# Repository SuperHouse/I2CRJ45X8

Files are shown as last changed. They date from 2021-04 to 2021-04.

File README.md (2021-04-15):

I2C to RJ45 Breakout (8 Port)
=============================
Copyright 2019-2021 SuperHouse Automation Pty Ltd  www.superhouse.tv  

8 RJ45 sockets connected to 32 I/O channels via I2C addressable
I/O controllers. Intended for use in building a home automation light
switch controller for connection to SuperHouse light switches.

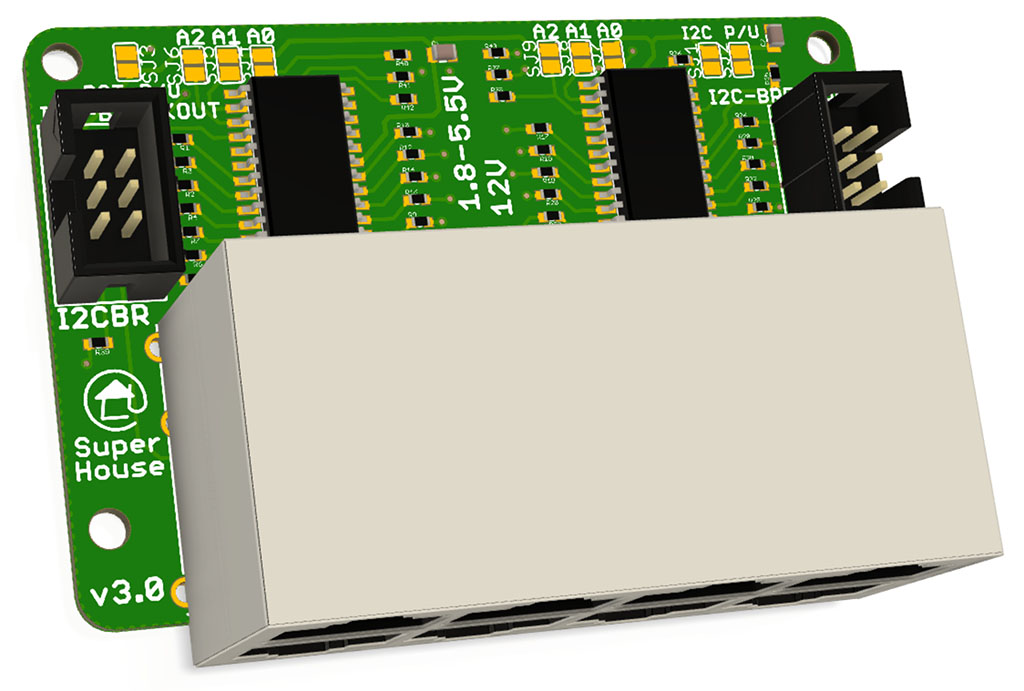
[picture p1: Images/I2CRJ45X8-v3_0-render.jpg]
I2C RJ45 Breakout PCB


Features:

 * 8 x RJ45 sockets for connection to light switches over Cat-5
 * I2C interface with interrupt output

This project has different versions:

 * 8-port version: https://github.com/superhouse/i2crj45x8
 * 16-port version: https://github.com/superhouse/i2crj45x16
 * 24-port version: https://github.com/superhouse/i2crj45x24
 * 24-port version with passthrough: https://github.com/superhouse/i2crj45x24pt

More information:

  http://www.superhouse.tv/i2crj45x8

INSTALLATION
------------
The design is saved as an EAGLE project. EAGLE PCB design software is
available from www.cadsoftusa.com free for non-commercial use. To use
this project download it and place the directory containing these files
into the "eagle" directory on your computer. Then open EAGLE and
navigate to the project.

CREDITS
-------
Designed by Jonathan Oxer jon@oxer.com.au

DISTRIBUTION
------------
The specific terms of distribution of this project are governed by the
license referenced below.

LICENSE
-------
Licensed under the TAPR Open Hardware License (www.tapr.org/OHL).
The "license" folder within this repository also contains a copy of
this license in plain text format.

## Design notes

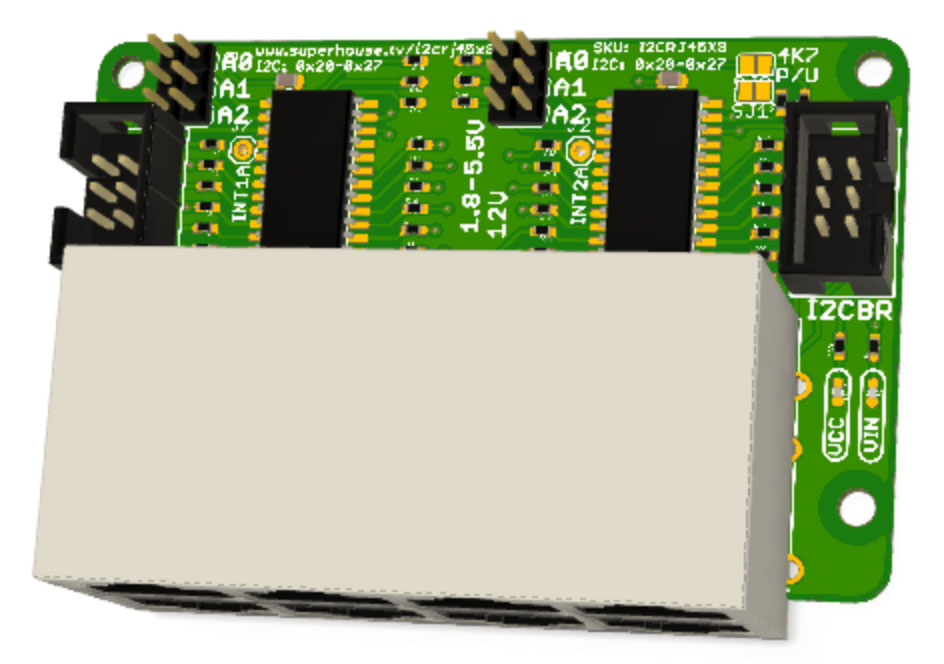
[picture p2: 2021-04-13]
Images/I2CRJ45X8-v2_2-render.jpg

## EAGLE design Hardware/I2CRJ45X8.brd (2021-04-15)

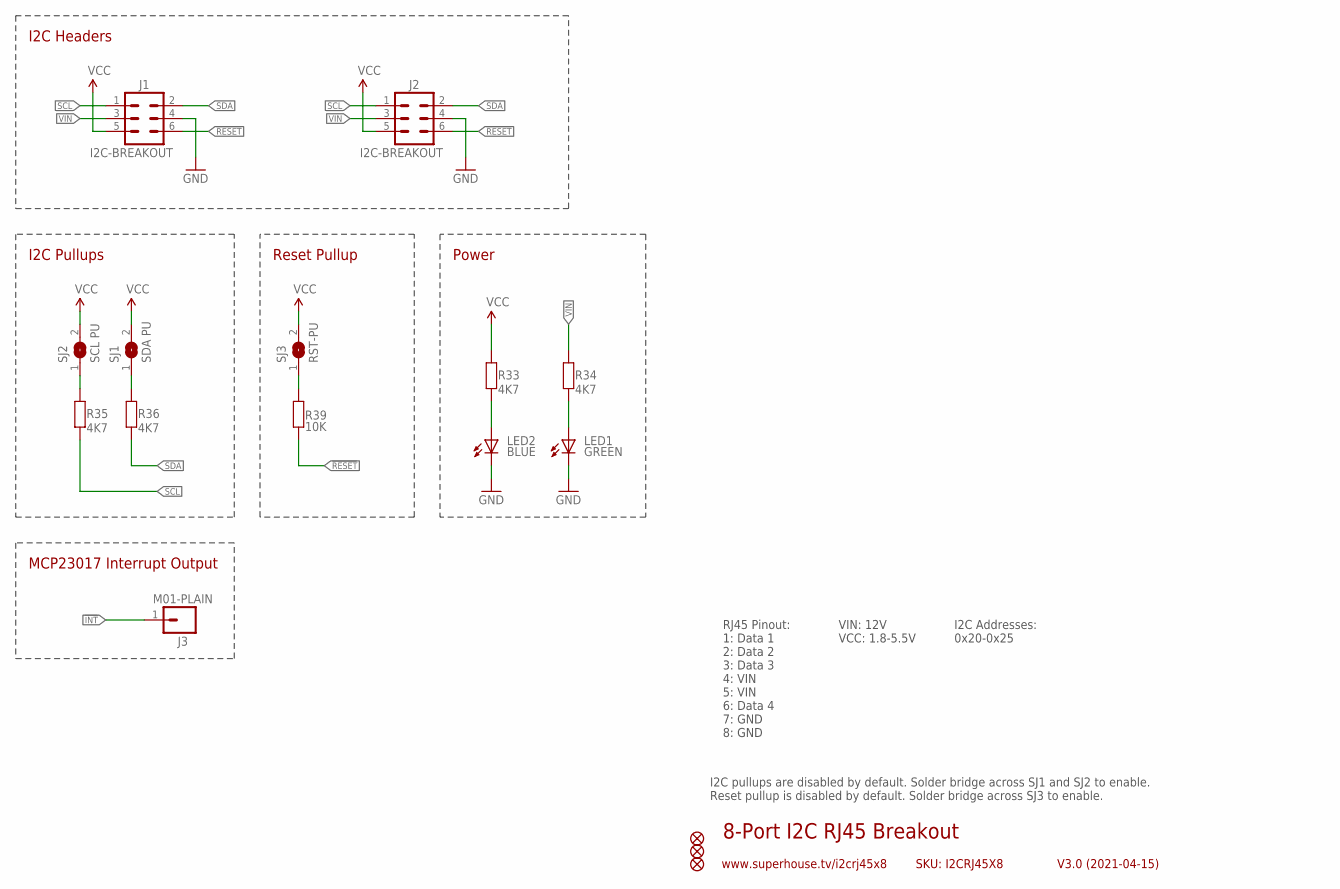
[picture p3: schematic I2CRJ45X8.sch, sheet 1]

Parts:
FID1, FID2, FID3: FIDUCIAL1X2.5; FIDUCIAL-1X2.5
J1, J2: I2C-BREAKOUT; 2X03-SHROUDED
J3: M01-PLAIN; 1X01
LED1: GREEN; LED-0603
LED2: BLUE; LED-0603
R33, R34, R35, R36: 4K7; R0603
R39: 10K; R0603
SJ1: SDA PU; SJ
SJ2: SCL PU; SJ
SJ3: RST-PU; SJ

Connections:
!INT: J3.1; also elsewhere on the board
!RESET: J1.6, J2.6, R39.1; also elsewhere on the board
GND: J1.4, J2.4, LED1.C, LED2.C; also elsewhere on the board
unnamed: R35.2, SJ2.1
unnamed: R36.2, SJ1.1
unnamed: R39.2, SJ3.1
unnamed: LED2.A, R33.1
unnamed: LED1.A, R34.1
SCL: J1.1, J2.1, R35.1; also elsewhere on the board
SDA: J1.2, J2.2, R36.1; also elsewhere on the board
VCC: J1.5, J2.5, R33.2, SJ1.2, SJ2.2, SJ3.2; also elsewhere on the board
VIN: J1.3, J2.3, R34.2; also elsewhere on the board

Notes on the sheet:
8-Port I2C RJ45 Breakout
V3.0 (2021-04-15)
www.superhouse.tv/i2crj45x8
SKU: I2CRJ45X8
RJ45 Pinout: 1: Data 1 2: Data 2 3: Data 3 4: VIN 5: VIN 6: Data 4 7: GND 8: GND
VIN: 12V VCC: 1.8-5.5V
I2C Addresses: 0x20-0x25
I2C Headers
MCP23017 Interrupt Output
I2C Pullups
I2C pullups are disabled by default. Solder bridge across SJ1 and SJ2 to enable. Reset pullup is disabled by default. Solder bridge across SJ3 to enable.
Power
Reset Pullup

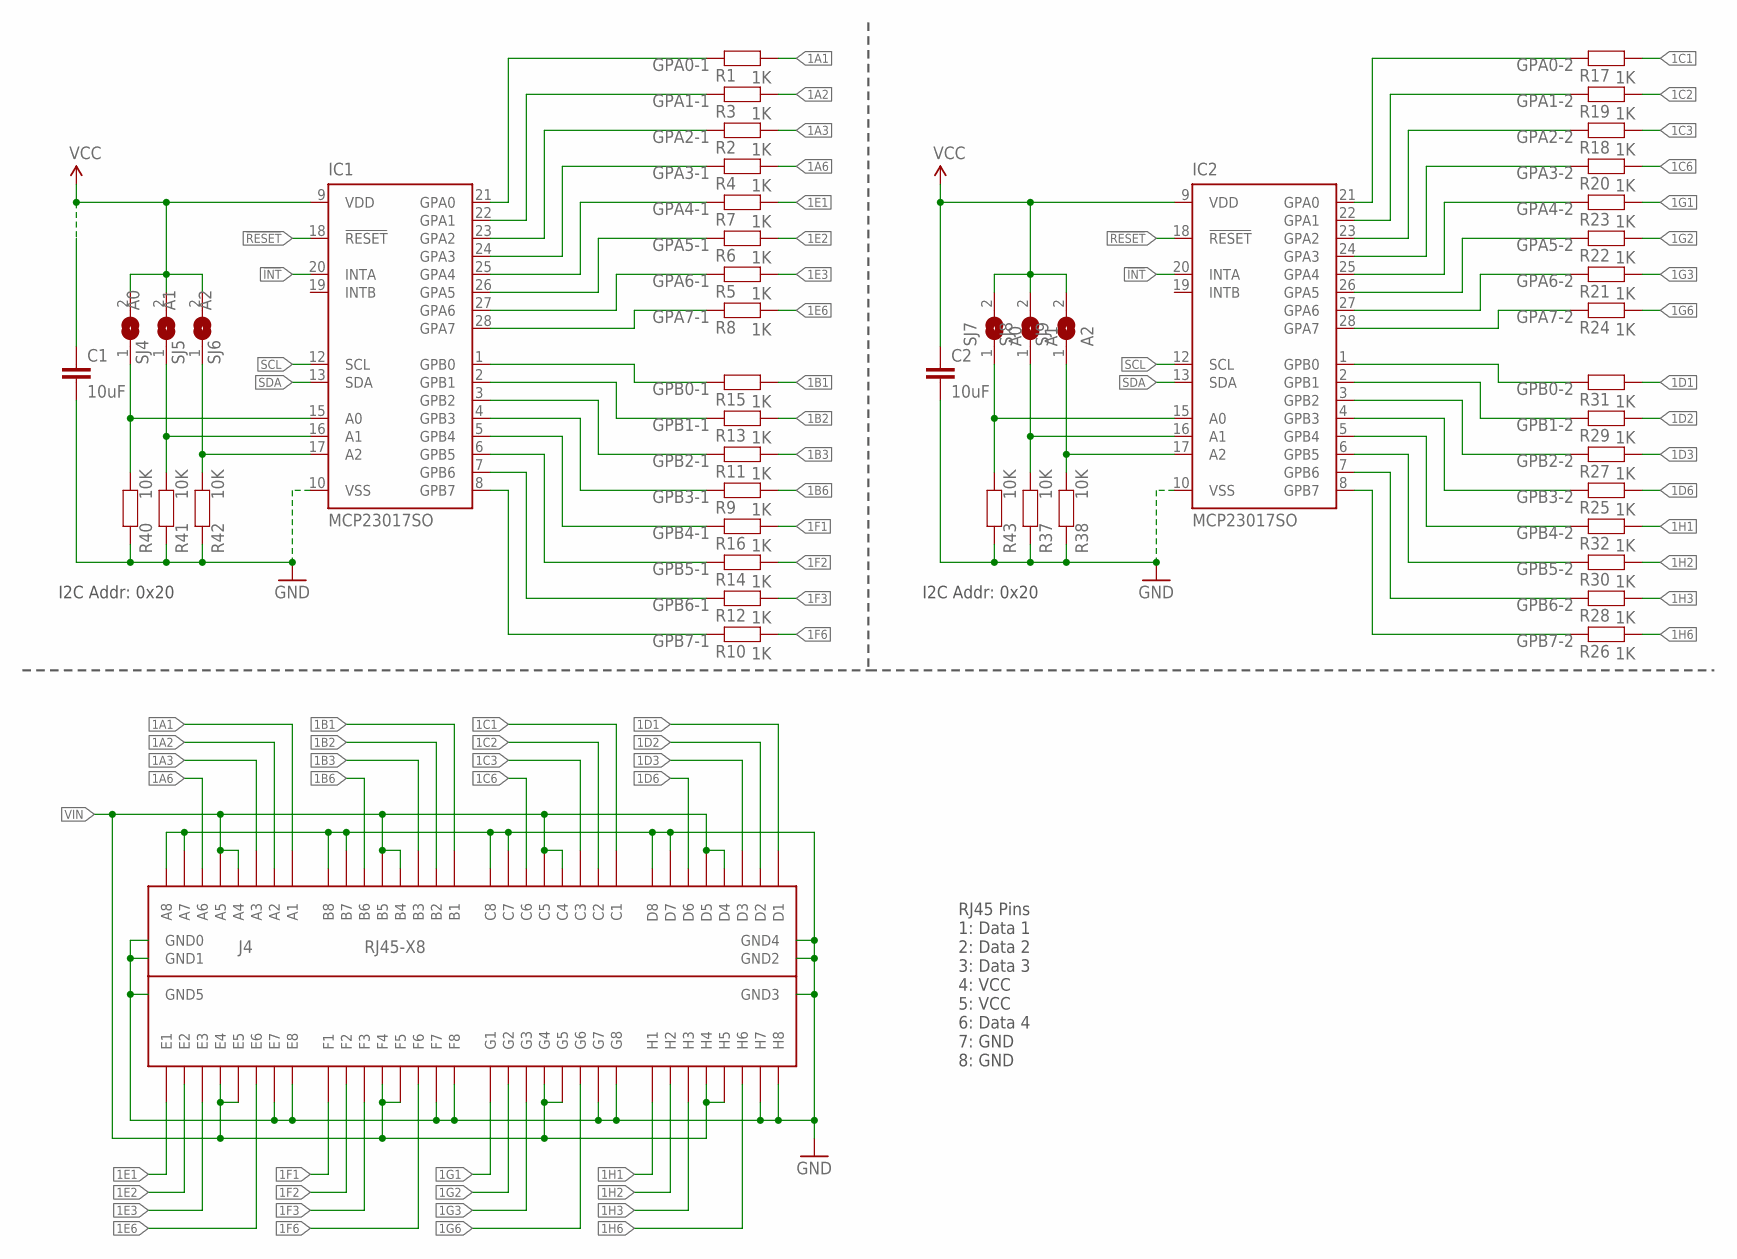
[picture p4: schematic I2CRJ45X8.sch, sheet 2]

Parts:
C1, C2: 10uF; C0805
IC1, IC2: MCP23017SO; SO28W
J4: RJ45-X8; RJ45-2X4
R1, R2, R3, R4, R5, R6, R7, R8, R9, R10, R11, R12, R13, R14, R15, R16, R17, R18, R19, R20, R21, R22, R23, R24, R25, R26, R27, R28, R29, R30, R31, R32: 1K; R0603
R37, R38, R40, R41, R42, R43: 10K; R0603
SJ4, SJ7: A0; SJ
SJ5, SJ8: A1; SJ
SJ6, SJ9: A2; SJ

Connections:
1A1: J4.A1, R1.2
1A2: J4.A2, R3.2
1A3: J4.A3, R2.2
1A6: J4.A6, R4.2
1B1: J4.B1, R15.2
1B2: J4.B2, R13.2
1B3: J4.B3, R11.2
1B6: J4.B6, R9.2
1C1: J4.C1, R17.2
1C2: J4.C2, R19.2
1C3: J4.C3, R18.2
1C6: J4.C6, R20.2
1D1: J4.D1, R31.2
1D2: J4.D2, R29.2
1D3: J4.D3, R27.2
1D6: J4.D6, R25.2
1E1: J4.E1, R7.2
1E2: J4.E2, R6.2
1E3: J4.E3, R5.2
1E6: J4.E6, R8.2
1F1: J4.F1, R16.2
1F2: J4.F2, R14.2
1F3: J4.F3, R12.2
1F6: J4.F6, R10.2
1G1: J4.G1, R23.2
1G2: J4.G2, R22.2
1G3: J4.G3, R21.2
1G6: J4.G6, R24.2
1H1: J4.H1, R32.2
1H2: J4.H2, R30.2
1H3: J4.H3, R28.2
1H6: J4.H6, R26.2
!INT: IC1.20 (INTA), IC2.20 (INTA); also elsewhere on the board
!RESET: IC1.18 (!RESET), IC2.18 (!RESET); also elsewhere on the board
GND: C1.2, C2.2, IC1.10 (VSS), IC2.10 (VSS), J4.A7, J4.A8, J4.B7, J4.B8, J4.C7, J4.C8, J4.D7, J4.D8, J4.E7, J4.E8, J4.F7, J4.F8, J4.G7, J4.G8, J4.GND0, J4.GND1, J4.GND2, J4.GND3, J4.GND4, J4.GND5, J4.H7, J4.H8, R37.1, R38.1, R40.1, R41.1, R42.1, R43.1; also elsewhere on the board
GPA0-1: IC1.21 (GPA0), R1.1
GPA0-2: IC2.21 (GPA0), R17.1
GPA1-1: IC1.22 (GPA1), R3.1
GPA1-2: IC2.22 (GPA1), R19.1
GPA2-1: IC1.23 (GPA2), R2.1
GPA2-2: IC2.23 (GPA2), R18.1
GPA3-1: IC1.24 (GPA3), R4.1
GPA3-2: IC2.24 (GPA3), R20.1
GPA4-1: IC1.25 (GPA4), R7.1
GPA4-2: IC2.25 (GPA4), R23.1
GPA5-1: IC1.26 (GPA5), R6.1
GPA5-2: IC2.26 (GPA5), R22.1
GPA6-1: IC1.27 (GPA6), R5.1
GPA6-2: IC2.27 (GPA6), R21.1
GPA7-1: IC1.28 (GPA7), R8.1
GPA7-2: IC2.28 (GPA7), R24.1
GPB0-1: IC1.1 (GPB0), R15.1
GPB0-2: IC2.1 (GPB0), R31.1
GPB1-1: IC1.2 (GPB1), R13.1
GPB1-2: IC2.2 (GPB1), R29.1
GPB2-1: IC1.3 (GPB2), R11.1
GPB2-2: IC2.3 (GPB2), R27.1
GPB3-1: IC1.4 (GPB3), R9.1
GPB3-2: IC2.4 (GPB3), R25.1
GPB4-1: IC1.5 (GPB4), R16.1
GPB4-2: IC2.5 (GPB4), R32.1
GPB5-1: IC1.6 (GPB5), R14.1
GPB5-2: IC2.6 (GPB5), R30.1
GPB6-1: IC1.7 (GPB6), R12.1
GPB6-2: IC2.7 (GPB6), R28.1
GPB7-1: IC1.8 (GPB7), R10.1
GPB7-2: IC2.8 (GPB7), R26.1
unnamed: IC1.17 (A2), R42.2, SJ6.1
unnamed: IC1.16 (A1), R41.2, SJ5.1
unnamed: IC1.15 (A0), R40.2, SJ4.1
unnamed: IC2.17 (A2), R38.2, SJ9.1
unnamed: IC2.16 (A1), R37.2, SJ8.1
unnamed: IC2.15 (A0), R43.2, SJ7.1
SCL: IC1.12 (SCL), IC2.12 (SCL); also elsewhere on the board
SDA: IC1.13 (SDA), IC2.13 (SDA); also elsewhere on the board
VCC: C1.1, C2.1, IC1.9 (VDD), IC2.9 (VDD), SJ4.2, SJ5.2, SJ6.2, SJ7.2, SJ8.2, SJ9.2; also elsewhere on the board
VIN: J4.A4, J4.A5, J4.B4, J4.B5, J4.C4, J4.C5, J4.D4, J4.D5, J4.E4, J4.E5, J4.F4, J4.F5, J4.G4, J4.G5, J4.H4, J4.H5; also elsewhere on the board

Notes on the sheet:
RJ45 Pins 1: Data 1 2: Data 2 3: Data 3 4: VCC 5: VCC 6: Data 4 7: GND 8: GND
I2C Addr: 0x20

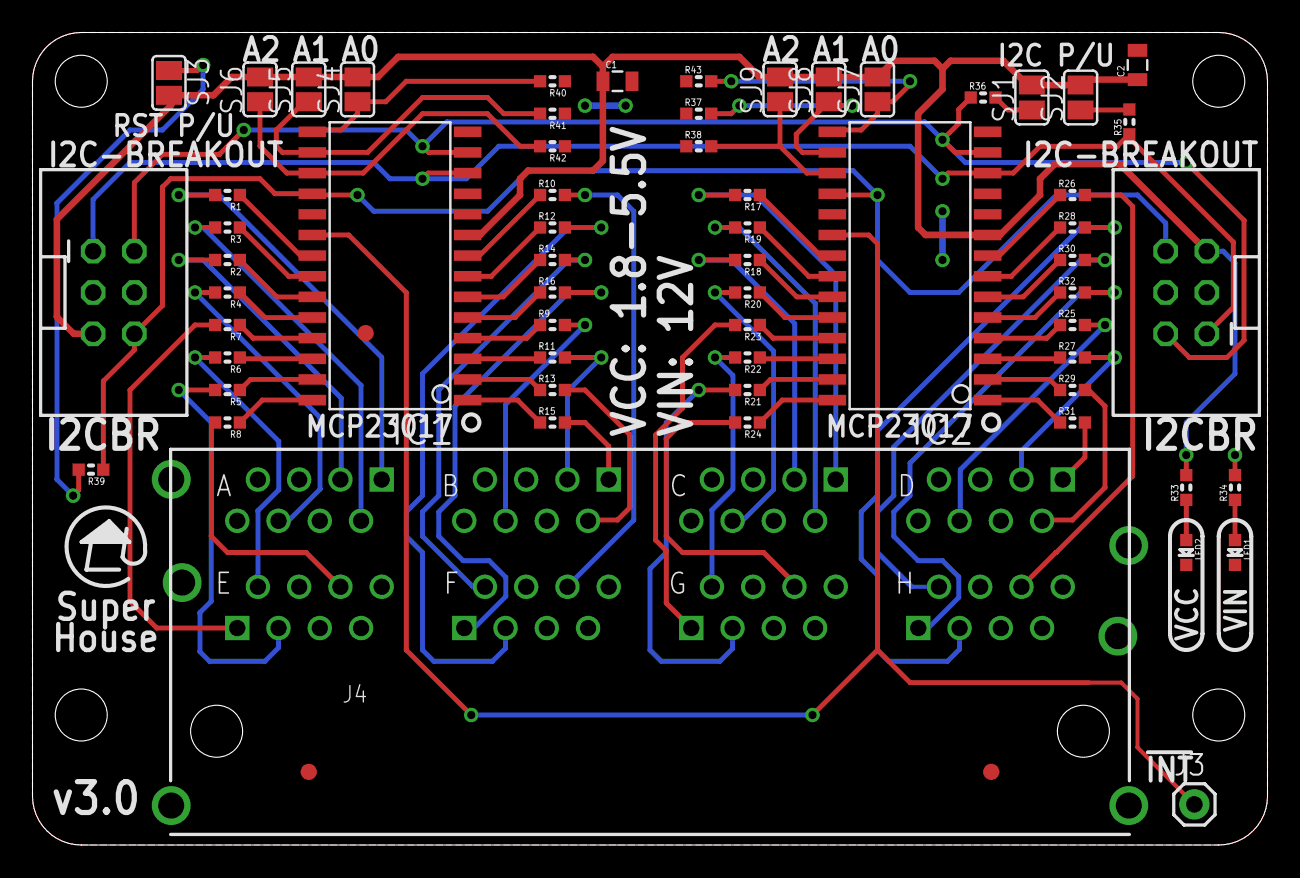
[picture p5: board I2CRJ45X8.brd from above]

Board: 2 copper layers, 76.0 x 50.0 mm, 65 parts (0 on the bottom side), 82 nets.

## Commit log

2019-09-07 Renamed project files for consistency with related projects
    [I2CRJ45X8.brd, I2CRJ45X8.sch]
2019-09-07 Board and schematic labelling
    [I2CRJ45X8.brd, I2CRJ45X8.sch]
2019-09-07 Part updates
    [I2CRJ45X8.brd, I2CRJ45X8.sch]
2019-09-07 Added fiducials
    [I2CRJ45X8.brd, I2CRJ45X8.sch]
2019-09-13 Switched fiducials to SuperHouse library
    [I2CRJ45X8.brd, I2CRJ45X8.sch]
2019-09-20 Start of conversion to I2C Breakout header (2x3 shrouded)
    [I2CRJ45X8.brd, I2CRJ45X8.sch]
2019-09-20 Routing for I2C Breakout headers
    [I2CRJ45X8.brd, I2CRJ45X8.sch]
2019-09-21 Experimenting with options for linking MCP reset to I2C Breakout reset
    [I2CRJ45X8.brd, I2CRJ45X8.sch]
2019-10-03 Routing for 2x3 I2C Breakout header
    [I2CRJ45X8.brd]
2020-04-08 Converted to I2C-BREAKOUT header for v2.0 release
    [I2CRJ45X8.brd, I2CRJ45X8.sch]
2021-04-12 Moved hardware files into subdirectory.
    [I2CRJ45X8.brd, I2CRJ45X8.sch]
2021-04-12 Reduced width of PCB. Adjusted mounting hole locations. Improved GND connections. Changed position of power LEDs.
    [I2CRJ45X8.brd, I2CRJ45X8.sch]
2021-04-13 Silkscreen, clearances, and DRC for v2.2 release.
    [I2CRJ45X8.brd]
2021-04-13 Added I2C pullups and silkscreen improvements.
    [I2CRJ45X8.brd, I2CRJ45X8.sch]
2021-04-13 Added IC part number to silkscreen.
    [I2CRJ45X8.brd]
2021-04-15 Renamed existing project files.
    [I2CRJ45X8-old.brd, I2CRJ45X8-old.sch]
2021-04-15 Moved in files from x16 version to begin conversion.
    [I2CRJ45X8-old.brd, I2CRJ45X8-old.sch, I2CRJ45X8.brd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]
2021-04-15 Major update based on 24-port project. Use solder jumpers for I2C address selection.
    [I2CRJ45X8.brd, I2CRJ45X8.sch]
